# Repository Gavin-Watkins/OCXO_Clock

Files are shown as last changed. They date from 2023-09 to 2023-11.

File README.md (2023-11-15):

# OCXO_Clock
Circuits, details and code for an Arduino based clock that uses a 10 MHz OCXO as a reference. 
# Introduction
This project describes a digital clock that uses a 10 MHz reference oscillator as its timing reference. This opens the possiblity of using a high stability OCXO reference to ensure high precision, beyond that of the convnetional clock. 
Precise time and frequency is an important requirement in many scientific applications. This used to be way beyond the scope of budget of many enthusiasts. There are those out there who go with the nickname Time Nut who scour online auctions for vintage atomic references like a Hewlett Packard 5061B Caesium clock so that they can poses a frequency reference with a stability accuracy of 2x10^-12. Recently these have come down in price to the point with Microchip offering a Rubidium Oscillator in a small compact package with an accuracy of <5x10^-11 for $2000. These may be beyond the scope of many, but temperature controlled crystal oscillators (TCXO) and oven controlled crystal oscillators (OCXO) with accuracies of 1x10^-6 and 5x10^-8 respectably. This is far better than the typical 20x10-6 of the 32.768 kHz crystals used in most digital clocks and the DS3231 which forms the basis of many digital clocks implemented on an Arduino or other micro-controller based platforms. Even worse is the 0.5% accuracy of the ceramic resonators used by the Arduino as a clock.
There are of course other options. Here in the UK the MSF transmissions at 60 kHz can be picked up by alarm clocks and watches to offer 2x10^-12 accuracy at home. Similar for the DCF77 in Germany at 77 kHz and WWV in the USA. GPS reception also offers an accuracy of 3x10^-8. All of this pushes the desire for a clock with an accuracy which is better than possible by the conventional 32.768 kHz crystal. This was the inception for this project, what accuracy is possible using modern crystal oscillators. 10 MHz has become the standard frequency for references, and so from hereon, it is assumed that this will be used. This project is highly flexible by its nature, so references with others frequencies could easily be used if desired.
# An OCXO Digital Clock
Previous work in this area had resulted in a divider chain to produce 32.768 kHz from 10 MHz. This was achieved by dividing 10 MHz by 1.25 x 2.5^6 using 74XX series discrete logic. The objective with this project was to build a clock from the ground up which could offer an accuracy far beyond anything which was consumer available. Although there is an appeal to building a clock completely in discrete logic, that limits the displays to generally seven segment LED types. For more complex displays, a micro-controller platform offers more options. The basic platform here is an Arduino Nano which offers far more processing power than is necessary for performing a simple hours-minutes-seconds type clock but is cheap and simple to use. There are many designs available online for such clocks, but they all inevitably rely on the DS3231 real-time clocks with its 2x10^-6 accuracy. One option could have been to drive the DS3231 with the divider chain mentioned above, but this was considered messy and would not really provide any great advantage.
The Arduino uses a 16 MHz ceramic resonator for its clock as mentioned above. It is not easy to change the frequency of this, to say 10 MHz without modify the firmware, and 16 MHz is used to derive the USB communications timing. Internet searches did not find any Arduino based clocks which used an external crystal reference surprisingly, so that was not an option. A physical switch to switch between 16 MHz and 10 MHz was an option, but not very practical. 
All microprocessors includes interrupts, which when triggered can pause the normal code running, move the registers to a memory location, carry out an interrupt service routine and then return to normal operation. These can generally be triggered by a clock driven timer or an external input on a dedicated pin. The Arduino includes three interrupt timers 
Timer0 and Timer1 can also be driven by an external clock source through the T0 and T1 pins. Timer0 is 8-bits where as Timer1 is 16 bit. The prescalars allows 2N division up to 1024, but are only accessible through the internal clock source. Setting CS10,CS11 and CS12 selects the external clock, but doing so bypasses the prescalar 
When used with an external clock on T0 or T1, the signal is sampled relative to the system clock. Using a maximum Nyquist sampling factor of 2.5, a realistic maximum external input frequency of 6.4 MHz results. Adding a 4 bit binary counter after the 10 MHz reference results in a 625 kHz, which when divided by 62500 (<216) results in 10 Hz. This triggers the interrupts and a chain of counters for  seconds, minutes and hours as shown in Figure 3.
Further dividers are implemented in software to generate 1 Hz, and then units and tens of the seconds, minutes and hours as separate LED displays are used for each. This will be explained in a further section which details the software and hardware implementation. 
# Components
An Arduino Nano is chosen for the platform, as it offers the same capabilities as the bigger platforms but is in a more compact form factor and is very cheap. Like most cheaper platforms it uses a ceramic resonator for timing, making it unsuitable for any critical applications. It does however include the usual SPI and I2C interfaces which make it easy to interface to modern displays with built in drivers. 
The OCXO (X1) chosen is a Raltron Electronics OX4120A-D3-5-10.000-3.3 available from Digikey. Any suitable OCXO could be used, even one with a difference frequency by changing the divider ratio. It also comes in a standard 14-pin dual-in-package (DIP) package. As the most expensive component, during most of the development a standard low cost 10 MHz oscillator was used. All of the components used in this project are either in DIP format or available in DIP modules for easy construction. The PCB is produced in KiCad and is made available both as KiCad files and gerbers through github for others to modify under the creative commons licence (File: OCXO_Clock_code_03_08_23). This allows components of different layouts to be used for example. Similarly, the 4-bit binary counter (U3) between OCXO and Arduino is a 74HC191. Any binary counter could be substituted for this provided it provides division. 
The OCXO is a 3.3V part, so a LD1117V33C linear low-drop-out (LDO) voltage regulator U2 derived this from the 5V system voltage. The 74HC191’s inputs are compatible with 3.3V logic levels so a translator is not necessary. The regulator is not critical, alternative LDO or switching types could be used. A second identical regulator U3 provides 3.3V to the displays. 
# Display
The display chosen are six Adafruit CharliePlex FeatherWing (A2-A7). These consist of 7x15 pixel array of LEDs which can be driven individually in a graphical mode or using fonts built into the Adafruit_IS31FL3731 library. They are communicated with by an I2C. The address of each can be set to one of two values: by default 0x74 but you can be changed to 0x77 by bridging a link. To drive multiple displays an I2C expander chip the TCA9548A (A8) is used. It has the address 0x77 (TCAADDR). 
The procedure for driving the TCA9548A is that first a command is sent to it to direct the input data to one of eight outputs. Then the command for the display digit is sent. The TCA9548A is only available in a surface mounted (SMT) package, but is available from Adafruit as the 2717 break out board in a DIP adapter board. This is available through Digikey and other online sellers. 
The CharliePlex displays in this project they are driven graphically with a separate look-up-table (LUT) for each character (0-9) and a whole byte for each pixel storing either a 0 or a 1. Although inefficient in the amount of memory space it takes up, this allows custom fonts to be easily programmed. A separate variable is used to set the brightness of the display. This could allow for dimming the brightness of the display at night if required. 
The seconds-minutes divider and minutes-hours divider are two separate LEDs. These are toggled on and off at a rate of 0.5 Hz by the one second divider chain. Their function or operation could be easily changed by modify the software.
# Input Interface
A single rotary encoder with a momentary press switch is used as the user interface. This gives the clock a modern minimalist feel. Separate press switches could of course be used with only minimum changes to the hardware and/or software. The rotary encoder software aims to mimic the operation of a monostable to reduce the impact of switch bounce. It was largely successful, although a few erroneous counts got through. Alternative rotary encoder software could easily be substituted into the clock. Although the prototype was built on one printed circuit board, it was designed so that it could easily be cut into two, so one mounted behind the other with header connectors for a more compact layout. This is reflected in the schematic with J1-4. 
# Software Details
The software is available here. Only two libraries, the aforementioned Adafruit_IS31FL3731 and the common Wire which enables serial communication including I2C and SPI. Next is the LUTs for the display. It is obvious by looking at them which digits are stored in which LUT.
The setup checks that each of the displays is functioning correctly and will send a command over the serial interface if not. Next Timer1 is setup for an external clock and to divide by 62499. This is 62499 and not 62500 as one instruction is needed to reset the counter.
The primary function of the main loop is to call the rotary encoder subroutine. The encoder subroutine aims to mimic a monostable to eliminate switch bounce. The code could easily be change here by a user. The displays are also driven here, but only when a toggle bit is enabled from the interrupt timer. Driving the displays in the graphical mode requires individually programming each of the 105 LEDs (15x7). There is also a brightness variable here which is user settable and the variable for increasing the brightness of a digit when it is being set. 
The Timer1 interrupt service routine is next which is called ten times a second. It consists of the divider chain. The LEDs between the seconds and minutes, and the minutes and hours are flashed here. Their function could be easily changed if desired. The final subroutine tcaselect deals with the TCA9548A I2C expander chip.
# PCB Layout
The schematic is exported to KiCad’s PCB layout. The final board is not complex and designed as a double sided board which is easy to solder. It is designed to be easily broken into two sections along the two cutouts either with a saw or scoring and snapping. Pads are fitted so that headers can be soldered in to plug the boards one behind the other making a more compact form suited to a desk clock. In this form, the “top” board holds the display and rotary encoder, with all else on the back board. The rotary encoder is fitting in the centre of the board, but this could course be moved to elsewhere and attached via flying leads. The prototype PCB was ordered through JCL in China, but any PCB fabrication house could be used for this or builders could do it themselves with a chemical process or routing machine. A photograph of the final board is shown in Figure 5, note there were some were some errors in the original layout which have been corrected in the final layout in Github.
The bottom portion of the board contains the Arduino, the I2C expander, the OCXO, divider chain and voltage regulators. The voltage regulators are mounted with the tabs facing outwards so heatsinks can be fitted if required. This wasn’t found necessary in the prototype, but if for example the displays are driven at a high current it maybe necessary. If the boards are mounted one behind the other, they are placed back to back, so all the components will be accessible from the back of the clock. This will make the design easier to hack if required. M3 holes are fitted in the board for easy mounting and these line up for the upper and lower parts of the board if they are mounted back to back with headers. Metal spacers can be fitted to provide the correct clearance and mechanical stability. 
Two mounting holes are also fitted above and below the OCXO. This is to provide mechanical stability. The OCXO is a relatively heavy component and held into the board simply by four bits in a DIP socket. This is also mounted vertically, so not particularly stable. A piece of wire can be threaded through the two holes with its ends twisted together to hold the OCXO is place. Cable ties could also be used, or a clamp if available. 
There are two sets of schematics, PCBs and gerbers files. This is because the TCA9548A modules comes in two flavours. The Adafruit one has a spacing of 0.6 inches between the rows (the "N" version) and the modules available on ebay have a 0.7 inch spacing. Double check which one you are using before fabricating the PCBs.
# Accuracy
The OX4120A-D3-5-10.000-3.3 is a fixed OCXO – it does not allow the ability to adjust the frequency. Alternative OCXOs do by applying a control voltage to one of the pins. This decision was made as its stability was believed to be high enough. However, the PCB could be easily modified to incorporate a trimmer resistor, or one fitted on flying leads so it is easily accessible. The problem then resides of how to check the accuracy of the clock and calibrate if needed. This requires a higher accuracy reference clock. The best the author had in his lab was a HP 53150A frequency counter with its own OCXO reference. It was last calibrated in 2013. When measuring the OCXO reference the frequency on the counter fluctuated between 10,000,000 and 9,999,999. This suggests an agreement and hence accuracy of better than <10-7. Being newer, it is likely that the OCXO in this clock is better than HP counter! 
# Construction
This project features several modules which are fitted with headers. These could be soldered directly to the PCB, but for convenience female sockets should be fitted as described in the BOM. This will allow parts to be changed in they become damaged or just for easy modification. Similarly, ICs sockets are fitted for U3 (74HC191) and X1 (OCXO).

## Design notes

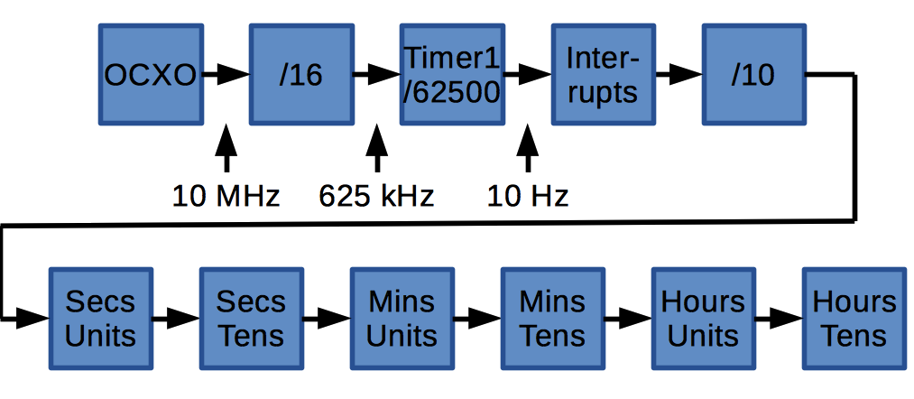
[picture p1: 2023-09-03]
OCXO Clock Arduino Divider Chain.png

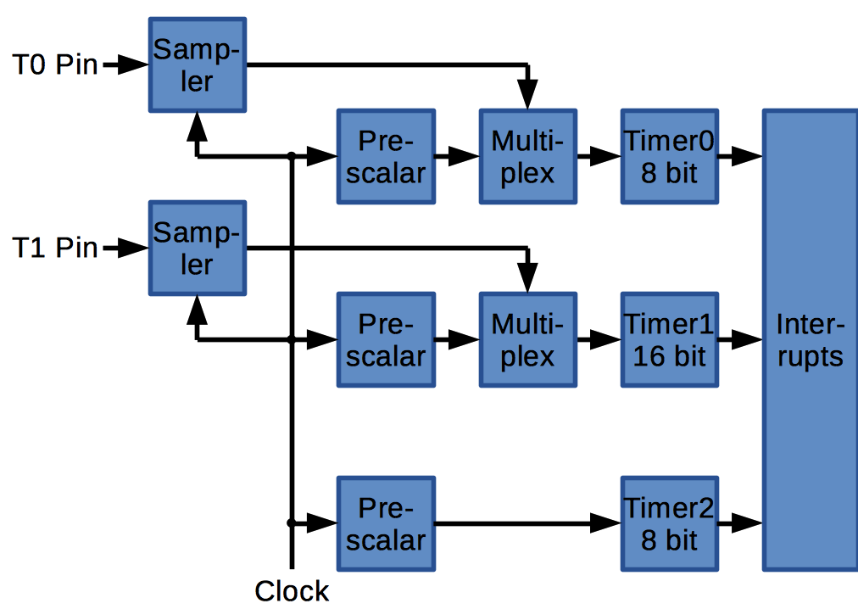
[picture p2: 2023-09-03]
OCXO Clock Arduino Timers.png

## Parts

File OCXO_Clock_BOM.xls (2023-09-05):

Ref | Qnty | Value | Cmp name | Description | Vendor | Vendor Part#
A1, | 1 | Arduino_Nano_Compatible | Arduino_Nano_v2.x | Arduino Nano v2.x | Digikey | 102010268
A2, A3, A4, A5, A6, A7, | 6 | Adafruit_Feather_Generic | Adafruit_Feather_Generic | Microcontroller module in various flavor, generic symbol | Digikey | 1528-1699-ND
A8, | 1 | 9548_Module | 9548_Module |  | Digikey | 1528-1363-ND
C1, C5, C6, C9, C11, | 5 | 100u | C_Polarized_Small | Polarized capacitor, small symbol | Digikey | ESY107M025AE3AA
C2, C3, C4, C7, C8, C10, C12, | 7 | 100n | C_Small | Unpolarized capacitor, small symbol | Digikey | R82DC3100DQ50J
D1, D2, D3, D4, | 4 | LED | LED | Light emitting diode | Digikey | 160-1704-ND
J1, J3 | 1 | Conn_01x07_Female | Conn_01x07_Female | Generic connector, single row, 01x07, script generated (kicad-library-utils/schlib/autogen/connector/) | Digikey | 1212-1114-ND
J2, J4 | 3 | Conn_01x07_Male | Conn_01x07_Male | Generic connector, single row, 01x07, script generated (kicad-library-utils/schlib/autogen/connector/) | Digikey | 350-80-164-00-001101
R1, R2, | 2 | 470R | R | Resistor | Digikey | 13-MF0207FRE52-470RCT-ND
R3, R4, R5, R6, R7, R8, R9, R10, | 8 | 10k | R | Resistor | Digikey | 13-MF0207FTE52-10KCT-ND
SW1, | 1 | RotaryEncoder_Switch | RotaryEncoder_Switch | Rotary encoder, dual channel, incremental quadrate outputs, with switch | Digikey | PEC12R-4215F-S0024-ND
U1, U2, | 2 | LD1117V33C | LT1083-3.3 | 7.5A 20V LDO Linear Regulator, Fixed Output 3.3V, TO-220/TO-263 | Digikey | 497-1492-5-ND
U3, | 1 | 74HC191 | 74LS191 | 4-bit Synchronous Up/Down binary Counter | Digikey | 296-49590-ND
X1, | 1 | OCXO-14 | OCXO-14 | Voltage-Controlled Crystal Clock Oscillator, DIP14-style metal package | Digikey | 2151-OX4120A-D3-5-10.000-3.3-ND
 |  |  |  | 14 pin IC socket | Digikey | ICS-316-T
 |  |  |  | 16 pin IC socket | Digikey | ICS-316-T

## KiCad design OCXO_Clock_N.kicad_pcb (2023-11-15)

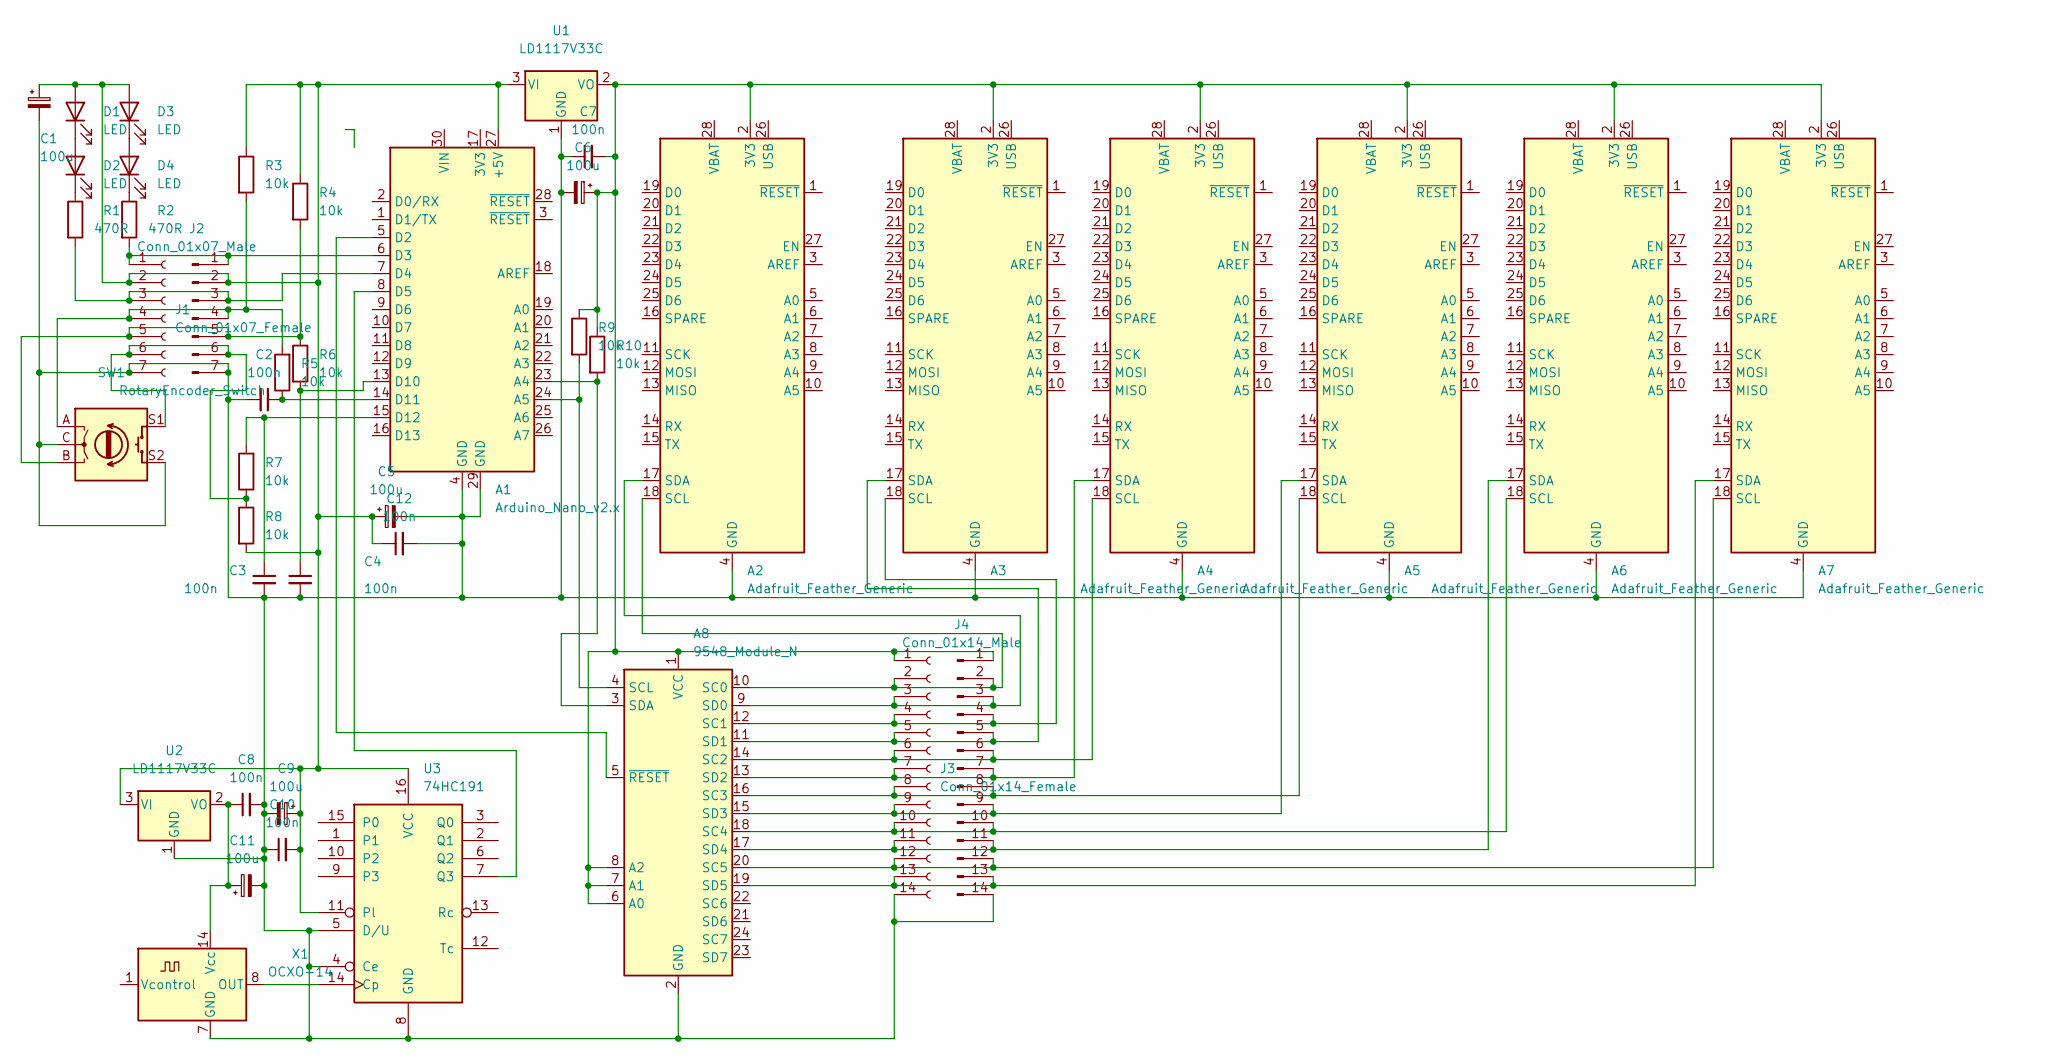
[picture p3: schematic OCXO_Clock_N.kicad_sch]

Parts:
A1: Arduino_Nano_v2.x; Arduino_Nano
A2, A3, A4, A5, A6, A7: Adafruit_Feather_Generic; Adafruit_Feather
A8: 9548_Module_N
C1, C5, C6, C9, C11: 100u; CP_Radial_D7.5mm_P2.50mm
C2, C3, C4, C7, C8, C10, C12: 100n; C_Rect_L7.0mm_W2.5mm_P5.00mm
D1, D2, D3, D4: LED; LED_D3.0mm
J1: Conn_01x07_Female; PinHeader_1x07_P2.54mm_Vertical
J2: Conn_01x07_Male; PinSocket_1x07_P2.54mm_Vertical
J3: Conn_01x14_Female; Molex_KK-254_AE-6410-14A_1x14_P2.54mm_Vertical
J4: Conn_01x14_Male; Molex_KK-254_AE-6410-14A_1x14_P2.54mm_Vertical
R1, R2: 470R; R_Axial_DIN0207_L6.3mm_D2.5mm_P10.16mm_Horizontal
R3, R4, R5, R6, R7, R8, R9, R10: 10k; R_Axial_DIN0207_L6.3mm_D2.5mm_P10.16mm_Horizontal
SW1: RotaryEncoder_Switch; RotaryEncoder_Bourns_Vertical_PEC12R-3xxxF-Sxxxx
U1, U2: LD1117V33C; TO-220-3_Vertical
U3: 74HC191; DIP-16_W7.62mm_LongPads
X1: OCXO-14; Oscillator_DIP-14

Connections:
unnamed: A1.5 (D2), A8.5 (~RESET)
unnamed: A1.6 (D3), J1.1, J2.1, R2.2
unnamed: A1.7 (D4), J1.3, J2.3, R1.2
unnamed: A1.8 (D5), U3.7 (Q3)
unnamed: A1.13 (D10), C4.1, R6.2
unnamed: A1.14 (D11), C2.1, R5.1
unnamed: A1.15 (D12), C3.1, R7.2
unnamed: A1.23 (A4), A8.3 (SDA), R10.2
unnamed: A1.24 (A5), A8.4 (SCL), R9.2
unnamed: A1.27 (+5V), C1.1, C5.1, C9.1, C10.2, C12.1, D1.2 (A), D3.2 (A), J1.2, J2.2, R3.1, R4.1, R8.2, U1.3 (VI), U2.3 (VI), U3.11 (Pl), U3.16 (VCC)
unnamed: A1.4 (GND), A1.29 (GND), A2.4 (GND), A3.4 (GND), A4.4 (GND), A5.4 (GND), A6.4 (GND), A7.4 (GND), A8.2 (GND), C1.2, C2.2, C3.2, C4.2, C5.2, C6.2, C7.1, C8.2, C9.2, C10.1, C11.2, C12.2, J1.7, J2.7, J3.14, J4.14, SW1.C, SW1.S2, U1.1 (GND), U2.1 (GND), U3.4 (Ce), U3.5 (D/U), U3.8 (GND), X1.7 (GND)
unnamed: A2.2 (3V3), A3.2 (3V3), A4.2 (3V3), A5.2 (3V3), A6.2 (3V3), A7.2 (3V3), A8.1 (VCC), A8.6 (A0), A8.7 (A1), A8.8 (A2), C6.1, C7.2, J3.1, J4.1, R9.1, R10.1, U1.2 (VO)
unnamed: A2.17 (SDA), A8.9 (SD0), J3.3, J4.3
unnamed: A2.18 (SCL), A8.10 (SC0), J3.2, J4.2
unnamed: A3.17 (SDA), A8.11 (SD1), J3.5, J4.5
unnamed: A3.18 (SCL), A8.12 (SC1), J3.4, J4.4
unnamed: A4.17 (SDA), A8.13 (SD2), J3.7, J4.7
unnamed: A4.18 (SCL), A8.14 (SC2), J3.6, J4.6
unnamed: A5.17 (SDA), A8.15 (SD3), J3.9, J4.9
unnamed: A5.18 (SCL), A8.16 (SC3), J3.8, J4.8
unnamed: A6.17 (SDA), A8.17 (SD4), J3.11, J4.11
unnamed: A6.18 (SCL), A8.18 (SC4), J3.10, J4.10
unnamed: A7.17 (SDA), A8.19 (SD5), J3.13, J4.13
unnamed: A7.18 (SCL), A8.20 (SC5), J3.12, J4.12
unnamed: C8.1, C11.1, U2.2 (VO), X1.14 (Vcc)
unnamed: D1.1 (K), D2.2 (A)
unnamed: D2.1 (K), R1.1
unnamed: D3.1 (K), D4.2 (A)
unnamed: D4.1 (K), R2.1
unnamed: J1.4, J2.4, R3.2, R5.2, SW1.A
unnamed: J1.5, J2.5, R4.2, R6.1, SW1.B
unnamed: J1.6, J2.6, R7.1, R8.1, SW1.S1
unnamed: U3.14 (Cp), X1.8 (OUT)

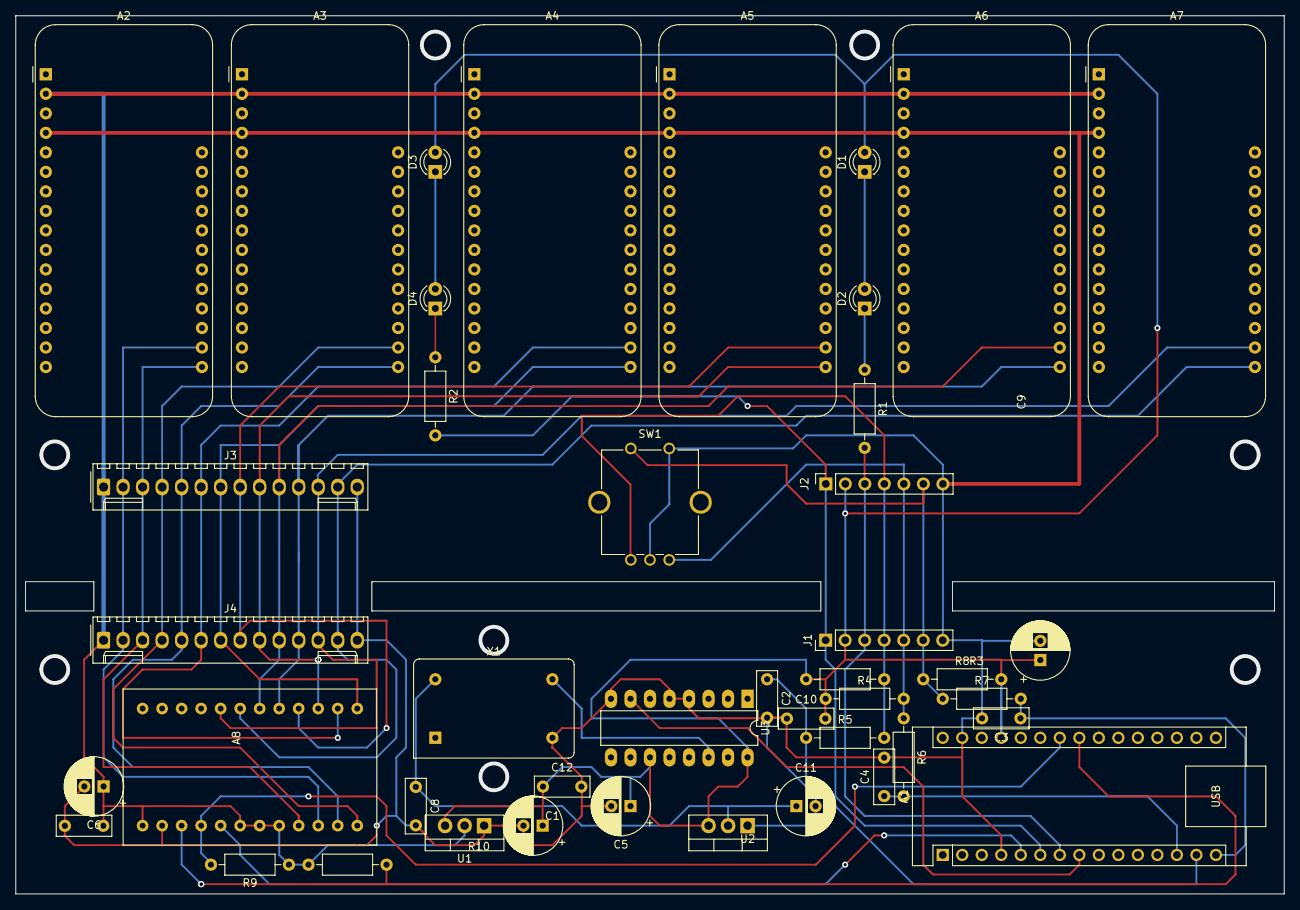
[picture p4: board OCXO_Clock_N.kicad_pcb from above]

Board: 2 copper layers, 165.1 x 114.3 mm, 43 parts (0 on the bottom side), 33 nets.

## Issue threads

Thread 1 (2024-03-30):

Available on PCBway?

csembroski, 2024-03-30:
Love the look of this project.  Have you shared the PCB setup at PCBway?  I'm great with a solder iron, but I have no experience getting boards manufactured.  I believe PCBway has a way to publish the setup on their platform?

Gavin-Watkins, 2024-03-30:
Hi,
Thanks for your interest in my project. I've not shared the PCB on PCBway. I probably can do that. Have you seen the details on my GitHub?
ThanksGavin

Yahoo Mail: Search, organise, conquer

  On Sat, 30 Mar 2024 at 14:14, Chuck ***@***.***> wrote:

Love the look of this project. Have you shared the PCB setup at PCBway? I'm great with a solder iron, but I have no experience getting boards manufactured. I believe PCBway has a way to publish the setup on their platform?

—
Reply to this email directly, view it on GitHub, or unsubscribe.
You are receiving this because you are subscribed to this thread.Message ID: ***@***.***>

csembroski, 2024-04-01:
Yes, I did look at your github but I’ve never had boards manufactured before.  I’m nearing retirement and want to build some projects before my eyes give out.  lolI built one of those Russian Nixie tube clocks a couple years ago but my wife got tangled up in the cord and it broke when it hit the tile floor.  Sent from my iPhoneOn Mar 30, 2024, at 1:19 PM, Gavin Watkins ***@***.***> wrote:
Hi,

Thanks for your interest in my project. I've not shared the PCB on PCBway. I probably can do that. Have you seen the details on my GitHub?

ThanksGavin

Yahoo Mail: Search, organise, conquer

  On Sat, 30 Mar 2024 at 14:14, Chuck ***@***.***> wrote:

Love the look of this project. Have you shared the PCB setup at PCBway? I'm great with a solder iron, but I have no experience getting boards manufactured. I believe PCBway has a way to publish the setup on their platform?

—

Reply to this email directly, view it on GitHub, or unsubscribe.

You are receiving this because you are subscribed to this thread.Message ID: ***@***.***>

—Reply to this email directly, view it on GitHub, or unsubscribe.You are receiving this because you authored the thread.Message ID: ***@***.***>

Gavin-Watkins, 2024-04-01:
Sorry to hear about your nixie tube clock. I've never built one, but have quite a lot of valve/tube radios and hifi equipment around the house that I'm pretty paranoid about.
I used JLC PCB, who were fairly straightforward. You just need to upload the gerbers in a zip file. They extract them and fabricate the PCB. A couple of guys at the IEEE Spectrum also made the clock to verify my design. I'm in the process of moving home - and actually country too. I may still have a few spare PCBs. Generally when you order it is quantites of five or so. All my stuff is being picked up tomorrow and it will be two months until we're able to start unpacking.

ThanksGavin

    On Monday, 1 April 2024 at 02:30:15 BST, Chuck Sembroski ***@***.***> wrote:

Yes, I did look at your github but I’ve never had boards manufactured before.  I’m nearing retirement and want to build some projects before my eyes give out.  lolI built one of those Russian Nixie tube clocks a couple years ago but my wife got tangled up in the cord and it broke when it hit the tile floor.  Sent from my iPhoneOn Mar 30, 2024, at 1:19 PM, Gavin Watkins ***@***.***> wrote:
Hi,

Thanks for your interest in my project. I've not shared the PCB on PCBway. I probably can do that. Have you seen the details on my GitHub?

ThanksGavin

Yahoo Mail: Search, organise, conquer

 On Sat, 30 Mar 2024 at 14:14, Chuck ***@***.***> wrote:

Love the look of this project. Have you shared the PCB setup at PCBway? I'm great with a solder iron, but I have no experience getting boards manufactured. I believe PCBway has a way to publish the setup on their platform?

—

Reply to this email directly, view it on GitHub, or unsubscribe.

You are receiving this because you are subscribed to this thread.Message ID: ***@***.***>

—Reply to this email directly, view it on GitHub, or unsubscribe.You are receiving this because you authored the thread.Message ID: ***@***.***>
—
Reply to this email directly, view it on GitHub, or unsubscribe.
You are receiving this because you commented.Message ID: ***@***.***>

csembroski, 2024-04-04:
Understood.  I built a tube amp from a kit a while ago, but I haven’t gotten much time to listen.  I took a programming job at NASA JSC working on the Artemis Gateway moon project and it sucks up all my free time just getting my feet under me.

I’ll put it on my todo list to get your gerbers and try JLC PCB.

Best wishes on a smooth move,
Chuck

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

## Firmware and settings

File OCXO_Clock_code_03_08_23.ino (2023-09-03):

#include <Wire.h>
#include <Adafruit_IS31FL3731.h>
#define TCAADDR 0x77
#define Reset_Pin 2 //reset pin for the demultiplexer
#define Seconds_LED 3 // LEDs between seconds and minutes which can be flashed etc
#define Minutes_LED 4 // LEDs between minutes and hours which can be flashed etc
#define Rotary_switch_pin 12 //switch on rotary encoder for setting time
#define Rotary_count_pin 10 //count input for rotary encoder
#define Rotary_direction_pin 11 //reset pin for the demultiplexer

Adafruit_IS31FL3731_Wing ledmatrix = Adafruit_IS31FL3731_Wing();

// so about to define a big old LUT. y is the horizontal which is 0-6 (7) and x the vertical which is 0-14 (15). 105 values
byte digits[] = {//7x15. Arranged like this so it is obvious what we are doing
  //Start of 0. LUTs take up too much space. Convert to binary and then decode on the other side
  0,1,1,1,1,1,0, // 62
  1,1,0,0,0,0,1, // 97
  1,1,0,0,0,0,1,
  1,1,1,0,0,0,1, // 103
  1,1,1,0,0,0,1,
  1,1,1,1,0,0,1, // 111
  1,1,0,1,0,0,1, // 105
  1,1,0,1,1,0,1, // 109
  1,1,0,0,1,0,1, // 101
  1,1,0,0,1,1,1, // 103
  1,1,0,0,0,1,1, // 99
  1,1,0,0,0,1,1,
  1,1,0,0,0,0,1,
  1,1,0,0,0,0,1,
  0,1,1,1,1,1,0,
  //Start of 1
  0,0,0,1,1,0,0, // 12
  0,0,1,1,1,0,0, // 28
  0,1,1,1,1,0,0, // 60
  0,0,0,1,1,0,0, 
  0,0,0,1,1,0,0,
  0,0,0,1,1,0,0,
  0,0,0,1,1,0,0,
  0,0,0,1,1,0,0,
  0,0,0,1,1,0,0,
  0,0,0,1,1,0,0,
  0,0,0,1,1,0,0,
  0,0,0,1,1,0,0,
  0,0,0,1,1,0,0,
  0,0,0,1,1,0,0,
  0,0,0,1,1,0,0,
  //Start of 2
  0,1,1,1,1,1,0,
  0,0,0,0,0,1,1,
  0,0,0,0,0,1,1,
  0,0,0,0,0,1,1,
  0,0,0,0,0,1,1,
  0,0,0,0,0,1,1,
  0,0,0,0,0,1,1,
  0,1,1,1,1,1,0,
  1,1,0,0,0,0,0,
  1,1,0,0,0,0,0,
  1,1,0,0,0,0,0,
  1,1,0,0,0,0,0,
  1,1,0,0,0,0,0,
  1,1,0,0,0,0,0,
  1,1,1,1,1,1,1,
  //Start of 3
  0,1,1,1,1,1,0,
  0,0,0,0,0,1,1,
  0,0,0,0,0,1,1,
  0,0,0,0,0,1,1,
  0,0,0,0,0,1,1,
  0,0,0,0,0,1,1,
  1,1,1,1,1,1,1,
  0,0,0,0,0,1,1,
  0,0,0,0,0,1,1,
  0,0,0,0,0,1,1,
  0,0,0,0,0,1,1,
  0,0,0,0,0,1,1,
  0,0,0,0,0,1,1,
  0,0,0,0,0,1,1,
  0,1,1,1,1,1,0,
  //Start of 4
  1,1,0,0,0,0,1,
  1,1,0,0,0,0,1,
  1,1,0,0,0,0,1,
  1,1,0,0,0,0,1,
  1,1,0,0,0,0,1,
  1,1,0,0,0,0,1,
  1,1,0,0,0,0,1,
  1,1,0,0,0,0,1,
  1,1,1,1,1,1,1,
  0,0,0,0,0,0,1,
  0,0,0,0,0,0,1,
  0,0,0,0,0,0,1,
  0,0,0,0,0,0,1,
  0,0,0,0,0,0,1,
  0,0,0,0,0,0,1,
  //Start of 5
  1,1,1,1,1,1,0,
  1,1,0,0,0,0,0,
  1,1,0,0,0,0,0,
  1,1,0,0,0,0,0,
  1,1,0,0,0,0,0,
  1,1,0,0,0,0,0,
  0,1,1,1,1,1,0,
  0,0,0,0,0,1,1,
  0,0,0,0,0,1,1,
  0,0,0,0,0,1,1,
  0,0,0,0,0,1,1,
  0,0,0,0,0,1,1,
  0,0,0,0,0,1,1,
  0,0,0,0,0,1,1,
  1,1,1,1,1,1,0,
  //Start of 6
  0,1,1,1,1,1,0,
  1,1,0,0,0,1,1,
  1,1,0,0,0,0,0,
  1,1,0,0,0,0,0,
  1,1,0,0,0,0,0,
  1,1,0,0,0,0,0,
  1,1,0,0,0,0,0,
  1,1,1,1,1,1,0,
  1,1,0,0,0,0,1,
  1,1,0,0,0,0,1,
  1,1,0,0,0,0,1,
  1,1,0,0,0,0,1,
  1,1,0,0,0,0,1,
  1,1,0,0,0,0,1,
  0,1,1,1,1,1,0,
  //Start of 7
  1,1,1,1,1,1,1,
  0,0,0,0,0,1,1,
  0,0,0,0,1,1,0,
  0,0,0,0,1,1,0,
  0,0,0,1,1,0,0,
  0,0,0,1,1,0,0,
  0,0,1,1,0,0,0,
  0,0,1,1,0,0,0,
  0,0,1,1,0,0,0,
  0,0,1,1,0,0,0,
  0,0,1,1,0,0,0,
  0,0,1,1,0,0,0,
  0,0,1,1,0,0,0,
  0,0,1,1,0,0,0,
  0,0,1,1,0,0,0,
  //Start of 8
  0,1,1,1,1,1,0,
  1,1,0,0,0,0,1,
  1,1,0,0,0,0,1,
  1,1,0,0,0,0,1,
  1,1,0,0,0,0,1,
  1,1,0,0,0,0,1,
  0,1,1,1,1,1,0,
  1,1,0,0,0,0,1,
  1,1,0,0,0,0,1,
  1,1,0,0,0,0,1,
  1,1,0,0,0,0,1,
  1,1,0,0,0,0,1,
  1,1,0,0,0,0,1,
  1,1,0,0,0,0,1,
  0,1,1,1,1,1,0,
  //Start of 9
  0,1,1,1,1,1,0,
  1,0,0,0,0,1,1,
  1,0,0,0,0,1,1,
  1,0,0,0,0,1,1,
  1,0,0,0,0,1,1,
  1,0,0,0,0,1,1,
  0,1,1,1,1,1,1,
  0,0,0,0,0,1,1,
  0,0,0,0,0,1,1,
  0,0,0,0,0,1,1,
  0,0,0,0,0,1,1,
  0,0,0,0,0,1,1,
  1,0,0,0,0,1,1,
  1,1,0,0,0,1,1,
  0,1,1,1,1,1,0};

void setCursor(int16_t x0, int16_t y0);
void setTextColor(uint16_t color);
void setTextColor(uint16_t color, uint16_t backgroundcolor);
void setTextSize(uint8_t size);
void setTextWrap(boolean w);

//int sig = 39; // Pin-T1 Pin-39 PD5
byte Count = 0;
boolean toggle2 = 0;
boolean Set_Flag = 0;
byte Set_Counter = 0; //1 is HoursTens, 2 is HoursMinutes, 3 is MinutesTens, 4 is MinutesUnits, 5 is SecondsTens, 6 is SecondsUnits
byte SecondsCount = 0;
byte MinutesCount = 0;
byte HoursCount = 0;
byte SecondsUnits = 0;
byte SecondsTens = 0;
byte MinutesUnits = 0;
byte MinutesTens = 0;
byte HoursUnits = 2;
byte HoursTens = 1;
byte Temp = 0;
byte x = 0;
byte y = 0;
byte brightness = 1;
byte SecondsUnitsSelect = 0;
byte SecondsTensSelect = 0;
byte MinutesUnitsSelect = 0;
byte MinutesTensSelect = 0;
byte HoursUnitsSelect = 0;
byte HoursTensSelect = 0;
int16_t Switch_Sampling = 0;
int Rotary_current = 0;
int Rotary_last = 0;
int Switch_current = 0;
int Switch_last = 0;
byte Switch_position = 0;
long Debouncedelay = 0;
int Rotary_direction = 0;// encoder0PinA = 10;
int Rotary_count = 0;//encoder0PinB = 11;
int Rotary_switch = 0;
byte CounterTemp = 0;
int Rotary_directionLast = HIGH; //encoder0PinALast = LOW;
int Rotary_switchLast = HIGH; //encoderSwitchLast = LOW;
int Rotary_directionCurrent = HIGH; //n = LOW;


// the setup function runs once when you press reset or power the board
void setup() {
  // initialize digital pin LED_BUILTIN as an output.
  Wire.begin();
  pinMode(LED_BUILTIN, OUTPUT);
  pinMode(Seconds_LED, OUTPUT);
  pinMode(Minutes_LED, OUTPUT);
  pinMode(Reset_Pin, OUTPUT); //reset for the multiplexer
  // initialize the rotary endoder inputs
  pinMode(Rotary_switch_pin, INPUT);
  pinMode(Rotary_count_pin, INPUT);
  pinMode(Rotary_direction_pin, INPUT);

  delay(200);
  digitalWrite(Reset_Pin,LOW);
  delay(200);
  digitalWrite(Reset_Pin,HIGH);
  delay(200);

  Serial.begin(9600);
  Serial.println("OCXO Clock");

  delay(200);

  tcaselect(0);
  if (! ledmatrix.begin()) {
    Serial.println("IS31 not found");
    while (1);
  }
  Serial.println("IS31 found!");

  tcaselect(1);
  if (! ledmatrix.begin()) {
    Serial.println("IS31 not found");
    while (1);
  }
  Serial.println("IS31 found!");

  tcaselect(2);
  if (! ledmatrix.begin()) {
    Serial.println("IS31 not found");
    while (1);
  }
  Serial.println("IS31 found!");

  tcaselect(3);
  if (! ledmatrix.begin()) {
    Serial.println("IS31 not found");
    while (1);
  }
  Serial.println("IS31 found!");

  tcaselect(4);
  if (! ledmatrix.begin()) {
    Serial.println("IS31 not found");
    while (1);
  }
  Serial.println("IS31 found!");

  tcaselect(5);
  if (! ledmatrix.begin()) {
    Serial.println("IS31 not found");
    while (1);
  }
  Serial.println("IS31 found!");
  cli();//stop interrupts
  //set timer1 interrupt at 5Hz
  TCCR1A = 0;// set entire TCCR1A register to 0
  TCCR1B = 0;// same for TCCR1B
  TCNT1  = 0;//initialize counter value to 0
  // set compare match register for 1hz increments
  OCR1A = 62499;// = (10*10^6) / 16 - 1 (must be <65536) Max we can do, so running at 10 Hz 
  // turn on CTC mode
  TCCR1B |= (1 << WGM12);
  // Set CS10 and CS12 bits for 1 prescaler
  //TCCR1B |= (1 << CS12) | (1 << CS10);  
  // External clock source on T1 pin. Clock on rising edge. This doesn't use the prescalar - unfortunately!
  TCCR1B |=  (1<<CS10) ;// External clock source on T1 pin. Clock on rising edge. PD5, no prescalar
  TCCR1B |=  (1<<CS11) ;
  TCCR1B |=  (1<<CS12) ;
  // enable timer compare interrupt
  TIMSK1 |= (1 << OCIE1A);
  
  sei();//allow interrupts
  
}

// the loop function runs over and over again forever
void loop() {
  /*Debouncedelay = 0;
  while (Debouncedelay < 65000) {
    Debouncedelay++;
  } */
  //Check the switch
  Switch_current = digitalRead(Rotary_switch_pin);
  if ((Switch_last == HIGH) && (Switch_current == LOW)) {
    Debouncedelay = 0;
    while (Debouncedelay < 65000) {
      Debouncedelay++;
    } 
    Switch_position++;
    if (Switch_position == 7) {
      Switch_position = 0;
    }
    //Serial.println (encoder0Pos);
    }  
  Switch_last = Switch_current;

  //selects the digit for setting the time
  if (Switch_position == 0){
    HoursTensSelect = 0;
    HoursUnitsSelect = 0;
    MinutesTensSelect = 0;
    MinutesUnitsSelect = 0;
    SecondsTensSelect = 0;
    SecondsUnitsSelect = 0;
  }

  if (Switch_position == 1){
    HoursTensSelect = 10;
    HoursUnitsSelect = 0;
    MinutesTensSelect = 0;
    MinutesUnitsSelect = 0;
    SecondsTensSelect = 0;
    SecondsUnitsSelect = 0;

    //Read the rotary counter
    CounterTemp = HoursTens;
    RotaryEncoder();
    HoursTens = CounterTemp;
    if (HoursTens > 2){
      HoursTens = 0;
    }
  }

  if (Switch_position == 2){
    HoursTensSelect = 0;
    HoursUnitsSelect = 10;
    MinutesTensSelect = 0;
    MinutesUnitsSelect = 0;
    SecondsTensSelect = 0;
    SecondsUnitsSelect = 0;

    //Read the rotary counter
    CounterTemp = HoursUnits;
    RotaryEncoder();
    HoursUnits = CounterTemp;
    if (HoursUnits > 9){
      HoursUnits = 0;
    }
    if ((HoursUnits > 4) && (HoursTens = 2)){
      HoursUnits = 0;
    }

  }

  if (Switch_position == 3){
    HoursTensSelect = 0;
    HoursUnitsSelect = 0;
    MinutesTensSelect = 10;
    MinutesUnitsSelect = 0;
    SecondsTensSelect = 0;
    SecondsUnitsSelect = 0;

     //Read the rotary counter
    CounterTemp = MinutesTens;
    RotaryEncoder();
    MinutesTens = CounterTemp;
    if (MinutesTens > 6){
      MinutesTens = 0;
    }   

  }

  if (Switch_position == 4){
    HoursTensSelect = 0;
    HoursUnitsSelect = 0;
    MinutesTensSelect = 0;
    MinutesUnitsSelect = 10;
    SecondsTensSelect = 0;
    SecondsUnitsSelect = 0;

    //Read the rotary counter
    CounterTemp = MinutesUnits;
    RotaryEncoder();
    MinutesUnits = CounterTemp;
    if (MinutesUnits > 9){
      MinutesUnits = 0;
    }   

  }

  if (Switch_position == 5){
    HoursTensSelect = 0;
    HoursUnitsSelect = 0;
    MinutesTensSelect = 0;
    MinutesUnitsSelect = 0;
    SecondsTensSelect = 10;
    SecondsUnitsSelect = 0;

     //Read the rotary counter
    CounterTemp = SecondsTens;
    RotaryEncoder();
    SecondsTens = CounterTemp;
    if (SecondsTens > 6){
      SecondsTens = 0;
    }   

  }

  if (Switch_position == 6){
    HoursTensSelect = 0;
    HoursUnitsSelect = 0;
    MinutesTensSelect = 0;
    MinutesUnitsSelect = 0;
    SecondsTensSelect = 0;
    SecondsUnitsSelect = 10;
 
    //Read the rotary counter
    CounterTemp = SecondsUnits;
    RotaryEncoder();
    SecondsUnits = CounterTemp;
    if (SecondsUnits > 9){
      SecondsUnits = 0;
    }   

  }

  if (toggle2){
    //Drive the display
   tcaselect(0);
    for (x = 0; x < 15; x++) // across the x axis, x is declared as a variable here
      for (y = 0; y < 7; y++) // across the y axis, y is declared as a variable here
        ledmatrix.drawPixel(x, y, (brightness + HoursTensSelect) * (digits[((x + (15 * (HoursTens))) * 7) + (6 - y)]));
    tcaselect(1);
    for (x = 0; x < 15; x++) // across the x axis, x is declared as a variable here
      for (y = 0; y < 7; y++) // across the y axis, y is declared as a variable here
        ledmatrix.drawPixel(x, y, (brightness + HoursUnitsSelect) * (digits[((x + (15 * (HoursUnits))) * 7) + (6 - y)]));
    //display the SecondsTens and SecondsUnits
    tcaselect(2);
    for (x = 0; x < 15; x++) // across the x axis, x is declared as a variable here
      for (y = 0; y < 7; y++) // across the y axis, y is declared as a variable here
        ledmatrix.drawPixel(x, y, (brightness + MinutesTensSelect) * (digits[((x + (15 * (MinutesTens))) * 7) + (6 - y)]));
    tcaselect(3);
    for (x = 0; x < 15; x++) // across the x axis, x is declared as a variable here
      for (y = 0; y < 7; y++) // across the y axis, y is declared as a variable here
        ledmatrix.drawPixel(x, y, (brightness + MinutesUnitsSelect) * (digits[((x + (15 * (MinutesUnits))) * 7) + (6 - y)]));
    tcaselect(4);
    for (x = 0; x < 15; x++) // across the x axis, x is declared as a variable here
      for (y = 0; y < 7; y++) // across the y axis, y is declared as a variable here
        ledmatrix.drawPixel(x, y, (brightness + SecondsTensSelect) * (digits[((x + (15 * (SecondsTens))) * 7) + (6 - y)]));
    tcaselect(5);
    for (x = 0; x < 15; x++) // across the x axis, x is declared as a variable here
      for (y = 0; y < 7; y++) // across the y axis, y is declared as a variable here
        ledmatrix.drawPixel(x, y, (brightness + SecondsUnitsSelect) * (digits[((x + (15 * (SecondsUnits))) * 7) + (6 - y)]));
  }      
  //delay(20);
}

void RotaryEncoder(){
  Debouncedelay = 0;
  while (Debouncedelay < 65000) {
    Debouncedelay++;
  } 
  Rotary_directionCurrent = digitalRead(Rotary_direction_pin);
  if ((Rotary_directionLast == HIGH) && (Rotary_directionCurrent == LOW)) {
    Debouncedelay = 0;
    while (Debouncedelay < 65000) {
      Debouncedelay++;
    } 
    if (digitalRead(Rotary_count_pin) == LOW) {
      CounterTemp--;
    } else {
      CounterTemp++;
    }
    Serial.println (CounterTemp);
  }
  Rotary_directionLast = Rotary_directionCurrent;
  Temp = CounterTemp;
}

ISR(TIMER1_COMPA_vect){
  
  if (Count == 9){ 
      Count = 0;
      SecondsUnits++;
      if (SecondsUnits >= 10){
      SecondsUnits = 0;
      SecondsTens++;
      }
      if (SecondsTens >= 6){
          SecondsTens = 0;
          MinutesUnits++;
      }
      if (MinutesUnits >= 10){
          MinutesUnits = 0;
          MinutesTens++;
      }
      if (MinutesTens >= 6){
          MinutesTens = 0;
          HoursUnits++;
      }
      if (HoursUnits >= 10){
          HoursUnits = 0;
          HoursTens++;
      }
      if (HoursUnits == 4 && HoursTens == 2){
          HoursUnits = 0;
          HoursTens = 0;
      }
      //Serial.println(SecondsUnits);
      /*Serial.print(HoursTens); 
      Serial.print(HoursUnits); 
      Serial.print(":"); 
      Serial.print(MinutesTens);
      Serial.print(MinutesUnits);
      Serial.print(":");
      Serial.print(SecondsTens);
      Serial.println(SecondsUnits);*/
      if (toggle2){
        digitalWrite(LED_BUILTIN,HIGH);
        digitalWrite(Seconds_LED,HIGH);
        digitalWrite(Minutes_LED,HIGH);
        toggle2 = 0;
      }
      else{
        digitalWrite(LED_BUILTIN,LOW);
        digitalWrite(Seconds_LED,LOW);
        digitalWrite(Minutes_LED,LOW);
        toggle2 = 1;
      }
    }
  else{
     Count++;
  }
}
void tcaselect(uint8_t i) {
  //digitalWrite(LED_BUILTIN,HIGH);
  if (i > 7) return;
  Wire.beginTransmission(TCAADDR);
  Wire.write(1 << i);
  Wire.endTransmission(); 
}
